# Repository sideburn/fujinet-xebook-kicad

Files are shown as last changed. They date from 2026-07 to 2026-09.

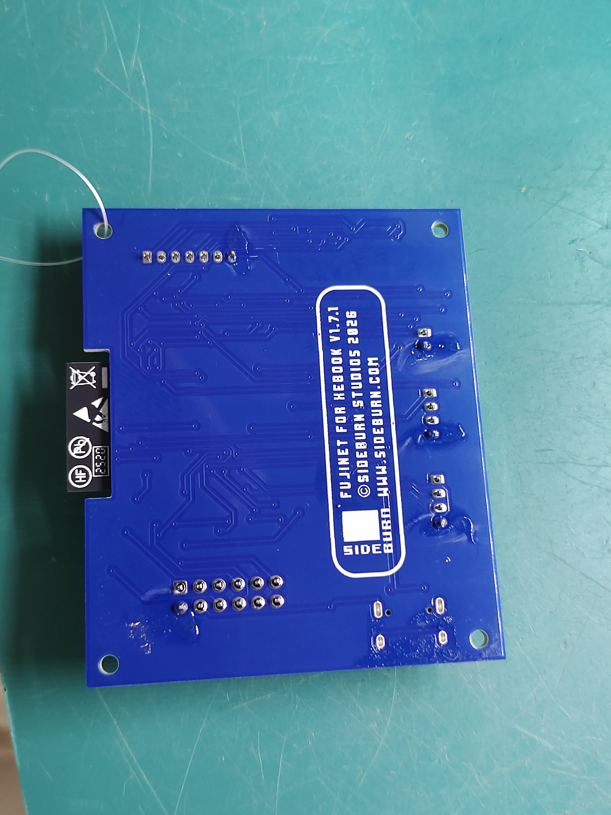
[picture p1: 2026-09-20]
Fab/as-built-1.0-PCBWay-T-1D22W845207A/Edits to PCBway/T-1D22W845207A/4716ba6a605b2589e788d23b78427af0.jpg

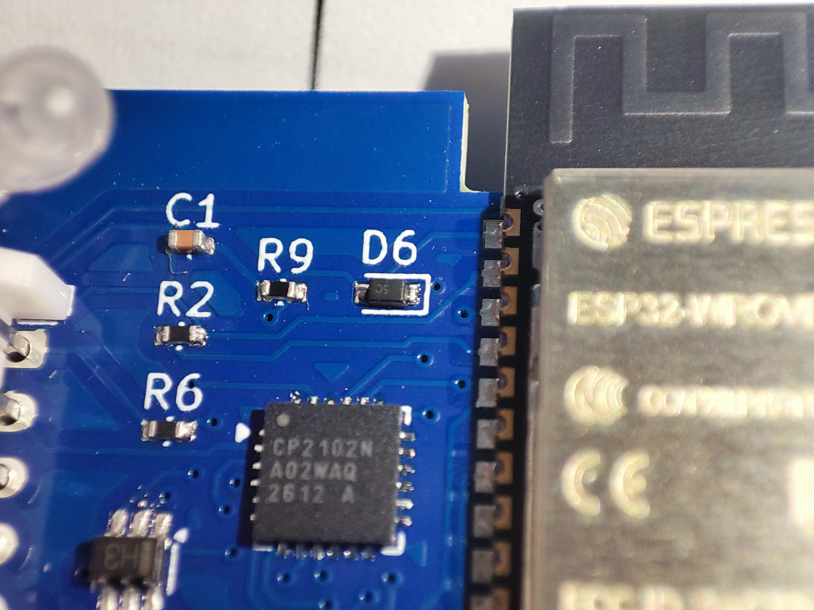
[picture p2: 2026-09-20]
Fab/as-built-1.0-PCBWay-T-1D22W845207A/Edits to PCBway/T-1D22W845207A_EQPic_0812140108/1_202608121354358581770.jpg

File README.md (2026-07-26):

# FN32ROV XEBook KiCad

A KiCad rebuild of the [FujiNet](https://fujinet.online/) FN32ROV WiFi/SIO adapter for
Atari 8-bit computers, adapted for permanent internal mounting inside an XEBook laptop
build.

This project is derived from the FN32ROV-1.7.1 release in
[FujiNetWIFI/fujinet-hardware](https://github.com/FujiNetWIFI/fujinet-hardware), which is
officially certified open source hardware by [OSHWA](https://oshwa.org) (UID
[US000651](https://certification.oshwa.org/us000651.html)). The original design is in
DipTrace; this project is a from-scratch rebuild in KiCad, since DipTrace's binary file
format has no viable automated conversion path into KiCad and this revision changes
enough of the board that preserving the original layout wasn't a goal.

## Status

Work in progress — schematic and PCB layout are still being built out. Not yet fabricated
or tested.

## What's different from FN32ROV-1.7.1

- The two external Atari SIO connectors (SIO plug + SIO receptacle pass-through) are
  replaced with a single low-profile right-angle 12-pin IDC header, hardwired directly to
  the host motherboard rather than daisy-chaining external SIO peripherals.
- The three status LEDs and three tactile buttons move off the PCB onto JST pigtails, so
  they can be panel-mounted separately from the board.
- The onboard microSD socket is retained, with an added parallel breakout header so the
  card can be relocated to an external board later without a further redesign.

Everything else (ESP32-WROVER-E, CP2102N USB-serial bridge, power path, SIO level
shifters) is carried over from the original design.

## Tooling

Built with KiCad 9. `kicad-cli sch erc` / `kicad-cli pcb drc` are used to verify the
design as it's built.

## License

[CERN Open Hardware Licence Version 2 - Strongly Reciprocal](LICENSE) (CERN-OHL-S-2.0),
matching the copyleft, share-alike spirit of the original OSHWA-certified design.

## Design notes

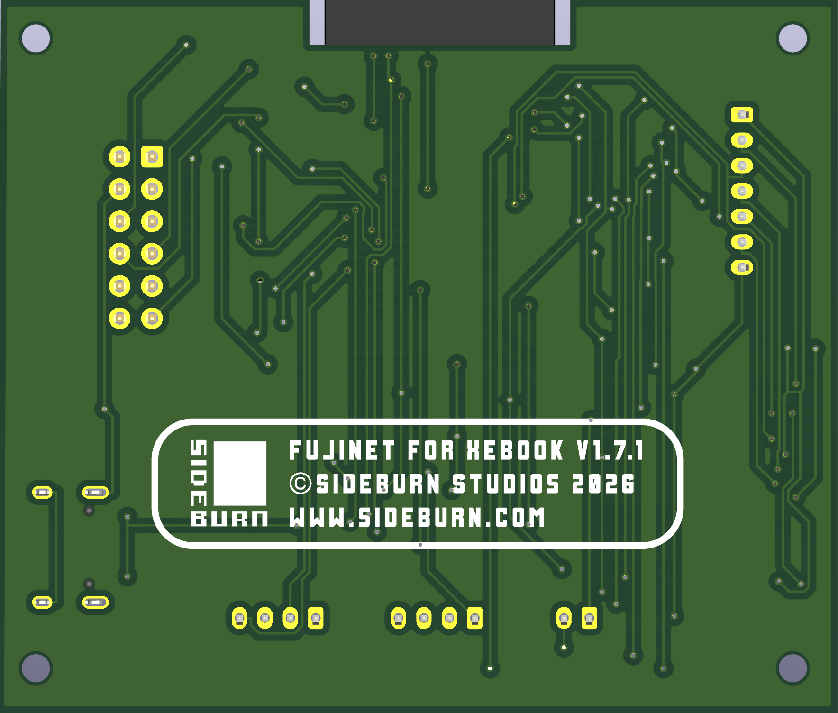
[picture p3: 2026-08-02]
Graphics/PCB_Back.png

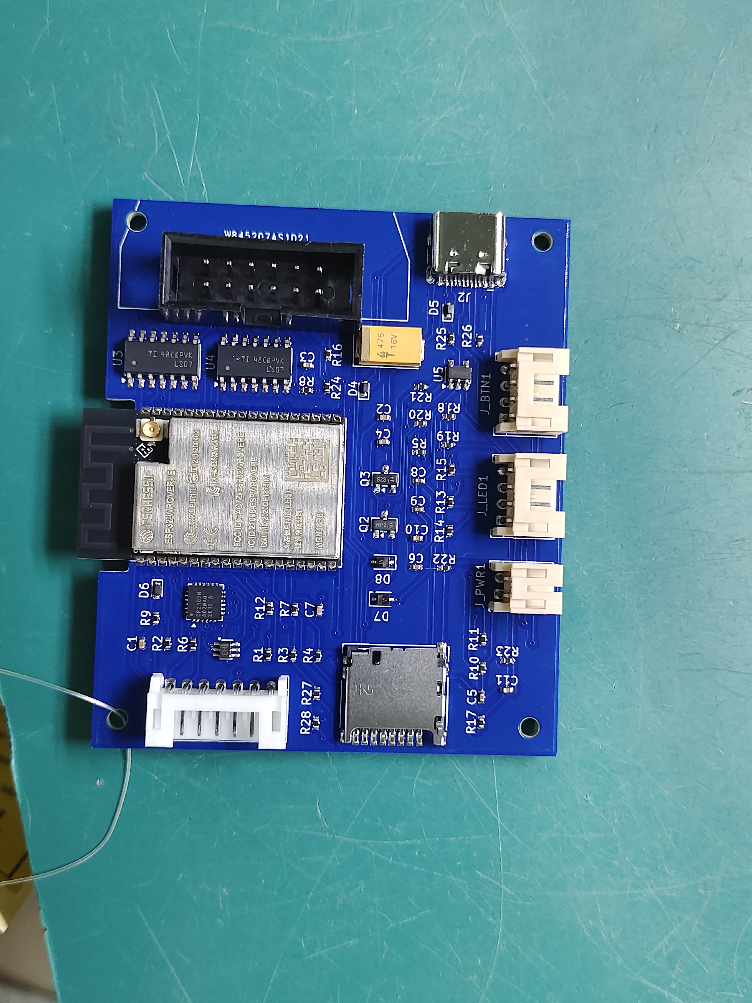
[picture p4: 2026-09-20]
Fab/as-built-1.0-PCBWay-T-1D22W845207A/Edits to PCBway/T-1D22W845207A/6a65568a0f6dcae3ce2b827522e64911.jpg

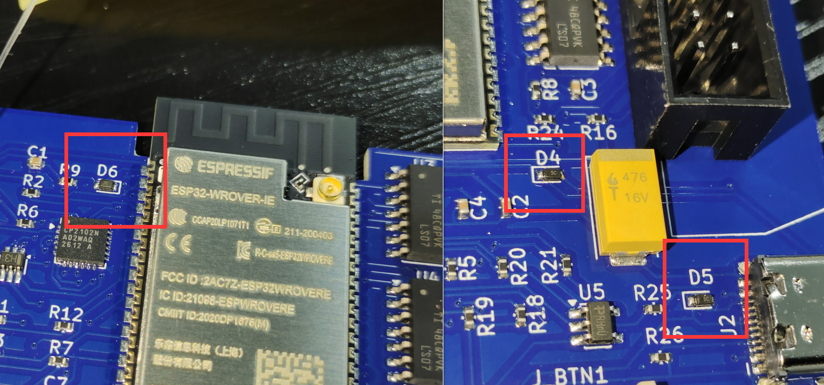
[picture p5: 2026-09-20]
Fab/as-built-1.0-PCBWay-T-1D22W845207A/Edits to PCBway/T-1D22W845207A/位号：D4,D5,D6,确认方向.png

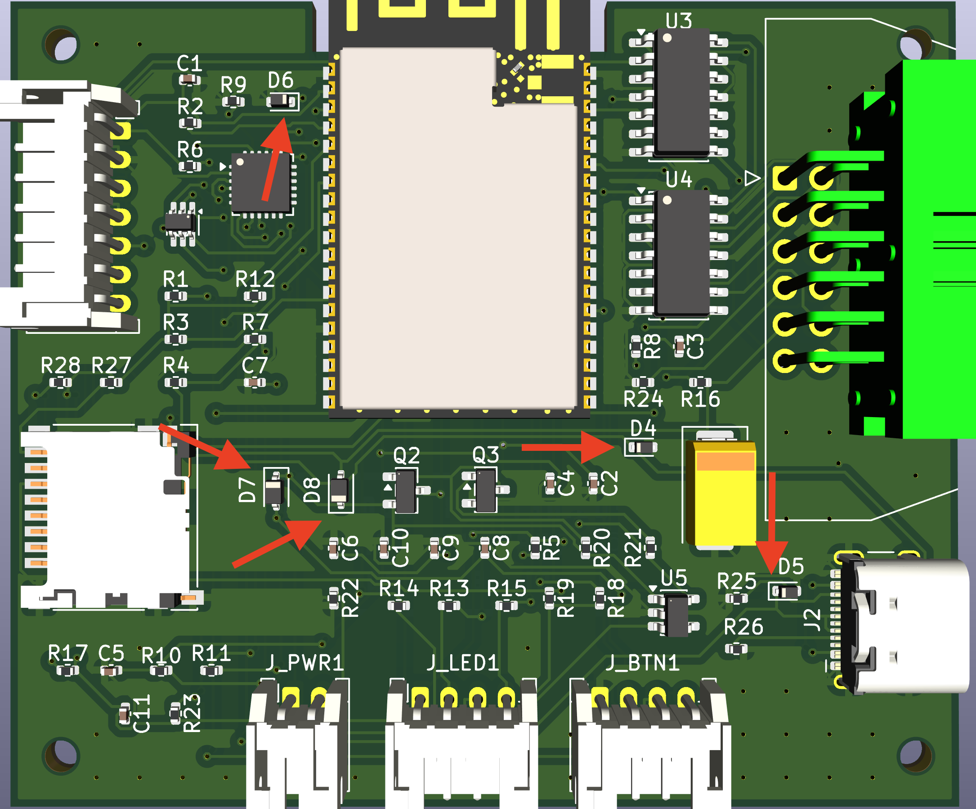
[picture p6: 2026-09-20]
Fab/as-built-1.0-PCBWay-T-1D22W845207A/Edits to PCBway/T-1D22W845207A_EQPic_0812140108/Screenshot 2026-08-11 at 11.21.06 PM.png

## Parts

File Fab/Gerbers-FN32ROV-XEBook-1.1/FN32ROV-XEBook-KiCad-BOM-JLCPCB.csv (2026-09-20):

Comment | Designator | Footprint | LCSC Part #
4.7uF 6.3V | C1 | Capacitor_SMD:C_0402_1005Metric | C23733
4.7uF 6.3V | C2 | Capacitor_SMD:C_0402_1005Metric | C23733
4.7uF 6.3V | C3 | Capacitor_SMD:C_0402_1005Metric | C23733
4.7uF 6.3V | C4 | Capacitor_SMD:C_0402_1005Metric | C23733
4.7uF 6.3V | C7 | Capacitor_SMD:C_0402_1005Metric | C23733
4.7uF 6.3V | C10 | Capacitor_SMD:C_0402_1005Metric | C23733
4.7uF 6.3V | C11 | Capacitor_SMD:C_0402_1005Metric | C23733
0.1uF 6.3V | C5 | Capacitor_SMD:C_0402_1005Metric | C1525
0.1uF 6.3V | C6 | Capacitor_SMD:C_0402_1005Metric | C1525
0.1uF 6.3V | C8 | Capacitor_SMD:C_0402_1005Metric | C1525
0.1uF 6.3V | C9 | Capacitor_SMD:C_0402_1005Metric | C1525
47uF 10V | C12 | Capacitor_Tantalum_SMD:CP_EIA-7343-31_Kemet-D | C503930
ESD5Z5.0T1G | D4 | Diode_SMD:D_SOD-523 | C2879719
ESD5Z5.0T1G | D5 | Diode_SMD:D_SOD-523 | C2879719
ESD5Z5.0T1G | D6 | Diode_SMD:D_SOD-523 | C2879719
PMEG2010BEA,115 | D7 | Diode_SMD:D_SOD-323 | C455041
PMEG2010BEA,115 | D8 | Diode_SMD:D_SOD-323 | C455041
USB-C 16P | J2 | LocalOverrides:USB_C_Receptacle_HCTL_HC-TYPE-C-16P-01A | C2894897
BTN_JST | J_BTN1 | Connector_JST:JST_PH_S4B-PH-K_1x04_P2.00mm_Horizontal | C265452
LED_JST | J_LED1 | Connector_JST:JST_PH_S4B-PH-K_1x04_P2.00mm_Horizontal | C265452
PWR_SW_JST | J_PWR1 | Connector_JST:JST_PH_S2B-PH-K_1x02_P2.00mm_Horizontal | C265016
SD_JST | J_SD1 | Connector_JST:JST_PH_S7B-PH-K_1x07_P2.00mm_Horizontal | C157917
SIO_IDC | J_SIO1 | Connector_IDC:IDC-Header_2x06_P2.54mm_Vertical | C9136
UMH3NTN | Q1 | Package_TO_SOT_SMD:SOT-363_SC-70-6 | C123008
DMP2035U-7 | Q2 | Package_TO_SOT_SMD:SOT-23 | C110499
DMG2302U | Q3 | Package_TO_SOT_SMD:SOT-23 | C96613
10K | R1 | Resistor_SMD:R_0402_1005Metric | C25744
10K | R2 | Resistor_SMD:R_0402_1005Metric | C25744
10K | R3 | Resistor_SMD:R_0402_1005Metric | C25744
10K | R5 | Resistor_SMD:R_0402_1005Metric | C25744
10K | R6 | Resistor_SMD:R_0402_1005Metric | C25744
10K | R8 | Resistor_SMD:R_0402_1005Metric | C25744
10K | R12 | Resistor_SMD:R_0402_1005Metric | C25744
10K | R17 | Resistor_SMD:R_0402_1005Metric | C25744
10K | R18 | Resistor_SMD:R_0402_1005Metric | C25744
10K | R19 | Resistor_SMD:R_0402_1005Metric | C25744
10K | R20 | Resistor_SMD:R_0402_1005Metric | C25744
10K | R22 | Resistor_SMD:R_0402_1005Metric | C25744
10K | R23 | Resistor_SMD:R_0402_1005Metric | C25744
10K | R27 | Resistor_SMD:R_0402_1005Metric | C25744
10K | R28 | Resistor_SMD:R_0402_1005Metric | C25744
1.2k | R4 | Resistor_SMD:R_0402_1005Metric | C25862
10K | R15 | Resistor_SMD:R_0402_1005Metric | C25744
2k | R7 | Resistor_SMD:R_0402_1005Metric | C413086
47.5K | R9 | Resistor_SMD:R_0402_1005Metric | C25896
1k | R10 | Resistor_SMD:R_0402_1005Metric | C11702
2.7k | R13 | Resistor_SMD:R_0402_1005Metric | C413089
30k | R14 | Resistor_SMD:R_0402_1005Metric | C25776
1k | R21 | Resistor_SMD:R_0402_1005Metric | C11702
22.1K | R11 | Resistor_SMD:R_0402_1005Metric | C163478
4.7K | R16 | Resistor_SMD:R_0402_1005Metric | C413001
2K | R24 | Resistor_SMD:R_0402_1005Metric | C413086
5.1K | R25 | Resistor_SMD:R_0402_1005Metric | C25905
5.1K | R26 | Resistor_SMD:R_0402_1005Metric | C25905
DM3D-SF | SD1 | Connector_Card:microSD_HC_Hirose_DM3D-SF | C719027
ESP32-WROVER-E-N16R8 | U1 | Espressif:ESP32-WROVER-E | C529589
CP2102N-A02-GQFN24R | U2 | Package_DFN_QFN:QFN-24-1EP_4x4mm_P0.5mm_EP2.6x2.6mm | C969151
74LS07DR | U3 | Package_SO:SOIC-14_3.9x8.7mm_P1.27mm | C371970
74LS07DR | U4 | Package_SO:SOIC-14_3.9x8.7mm_P1.27mm | C371970
XC6220B331MR | U5 | Package_TO_SOT_SMD:SOT-23-5 | C3040644

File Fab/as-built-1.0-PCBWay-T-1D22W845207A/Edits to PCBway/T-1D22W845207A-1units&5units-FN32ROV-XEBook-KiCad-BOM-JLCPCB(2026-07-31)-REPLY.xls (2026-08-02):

PCBWay Bom Quotation, Product No.:T-1D22W845207A
Item # | *Designator | *Qty | Manufacturer | *Mfg Part # | Description / Value | *Package/Footprint | *Unit Price(1 unit) | *Total | *Delivery Time | *Unit Price(5 units) | *Total | *Delivery Time | *Actual Purchase Mfg Part # | *PCBWay Note | Customer Reply | PCBWay Update
1 | C1 C2 C3 C4 C7 C10 C11 | 7 | SAMSUNG(三星) | C23733 | 4.7uF 6.3V | Capacitor_SMD:C_0402_1005Metric | $0.160 | $0.000 |  | $0.046 | $0.000 |  | CL05A475MP5NRNC | The correct voltage for the listed Part Number [CL05A475MP5NRNC] is indeed [10V], not [6.3V].Please confirm. | Confirmed, the 10V-rated substitute is acceptable. It exceeds our 6.3V spec (more headroom), no functional impact. Please proceed.
2 | C5 C6 C8 C9 | 4 | SAMSUNG(三星) | C1525 | 0.1uF 6.3V | Capacitor_SMD:C_0402_1005Metric | $0.151 | $0.000 |  | $0.050 | $0.000 |  | CL05B104KO5NNNC | The correct voltage for the listed Part Number [CL05B104KO5NNNC] is indeed [16V], not [6.3V].Please confirm. | Confirmed, the 16V-rated substitute is acceptable. It exceeds our 6.3V spec (more headroom), no functional impact. Please proceed.
3 | C12 | 1 | TORCH(火炬) | C503930 | 47uF 10V | Capacitor_Tantalum_SMD:CP_EIA-7343-31_Kemet-D | $3.001 | $0.000 |  | $1.491 | $0.000 |  | CA45-D-16V-47uF-K | The correct voltage for the listed Part Number [CA45-D-16V-47uF-K] is indeed [16V], not [10V].Please confirm. | Confirmed, the 16V-rated substitute is acceptable. It exceeds our 10V spec (more headroom), no functional impact. Please proceed.
4 | D4 D5 D6 | 3 | CBI(创基) | C2879719 | ESD5Z5.0T1G | Diode_SMD:D_SOD-523 | $0.328 | $0.000 |  | $0.066 | $0.000 |  | DESD5Z5.0
5 | D7 D8 | 2 | Nexperia(安世) | C82288 | PMEG2010ER,115 | Diode_SMD:D_SOD-323 | $0.239 | $0.000 |  | $0.102 | $0.000 |  | PMEG2010BEA,115
6 | J2 | 1 | HCTL(华灿天禄) | C2894897 | USB-C 16P | LocalOverrides:USB_C_Receptacle_HCTL_HC-TYPE-C-16P-01A | $0.904 | $0.000 |  | $0.259 | $0.000 |  | HC-TYPE-C-16P-01A
7 | J_BTN1 | 1 | JST | C265452 | BTN_JST | Connector_JST:JST_PH_S4B-PH-K_1x04_P2.00mm_Horizontal | $1.587 | $0.000 |  | $0.317 | $0.000 |  | S4B-PH-K(LF)(SN)
8 | J_LED1 | 1 | JST | C265452 | LED_JST | Connector_JST:JST_PH_S4B-PH-K_1x04_P2.00mm_Horizontal | $1.587 | $0.000 |  | $0.317 | $0.000 |  | S4B-PH-K(LF)(SN)
9 | J_PWR1 | 1 | JST | C265016 | PWR_SW_JST | Connector_JST:JST_PH_S2B-PH-K_1x02_P2.00mm_Horizontal | $0.869 | $0.000 |  | $0.174 | $0.000 |  | S2B-PH-K(LF)(SN)
10 | J_SD1 | 1 | JST | C157917 | SD_JST | Connector_JST:JST_PH_S7B-PH-K_1x07_P2.00mm_Horizontal | $1.480 | $0.000 |  | $0.296 | $0.000 |  | S7B-PH-K-S(LF)(SN)
11 | J_SIO1 | 1 |  |  | SIO_IDC | LocalOverrides:IDC-Header_2x06_P2.54mm_Latch_Horizontal | $0.391 | $0.000 |  | $0.130 | $0.000 |  | 2.54-2*6P简牛
12 | Q1 | 1 | ROHM(罗姆) | C123008 | UMH3NTN | Package_TO_SOT_SMD:SOT-363_SC-70-6 | $1.068 | $0.000 |  | $0.193 | $0.000 |  | UMH3NTN
13 | Q2 | 1 | DIODES(美台) | C110499 | DMP2035U-7 | Package_TO_SOT_SMD:SOT-23 | $0.517 | $0.000 |  | $0.172 | $0.000 |  | DMP2035U-7
14 | Q3 | 1 | DIODES(美台) | C96613 | DMG2302U | Package_TO_SOT_SMD:SOT-23 | $0.316 | $0.000 |  | $0.105 | $0.000 |  | DMG2302U-7
15 | R1 R2 R3 R5 R6 R8 R12 R17 R18 R19 R20 R22 R23 R27 R28 | 15 | UNI-ROYAL(厚声) | C25744 | 10K | Resistor_SMD:R_0402_1005Metric | $0.015 | $0.000 |  | $0.005 | $0.000 |  | 0402WGF1002TCE
16 | R4 R15 | 2 | UNI-ROYAL(厚声) | C25862 | 1.2k | Resistor_SMD:R_0402_1005Metric | $0.069 | $0.000 |  | $0.019 | $0.000 |  | 0402WGF1201TCE
17 | R7 R24 | 2 | PANASONIC(松下) | C413086 | 2k | Resistor_SMD:R_0402_1005Metric | $0.254 | $0.000 |  | $0.069 | $0.000 |  | ERJ2RKF2001X
18 | R9 | 1 | UNI-ROYAL(厚声) | C25896 | 47.5K | Resistor_SMD:R_0402_1005Metric | $0.132 | $0.000 |  | $0.032 | $0.000 |  | 0402WGF4752TCE
19 | R10 R14 R21 | 3 | UNI-ROYAL(厚声) | C11702 | 1k | Resistor_SMD:R_0402_1005Metric | $0.048 | $0.000 |  | $0.015 | $0.000 |  | 0402WGF1001TCE
20 | R11 | 1 | YAGEO(国巨) | C163478 | 22.1K | Resistor_SMD:R_0402_1005Metric | $0.132 | $0.000 |  | $0.032 | $0.000 |  | RC0402FR-0722K1L
21 | R16 | 1 | PANASONIC(松下) | C413001 | 4.7K | Resistor_SMD:R_0402_1005Metric | $0.485 | $0.000 |  | $0.116 | $0.000 |  | ERJ2GEJ472X
22 | R25 R26 | 2 | UNI-ROYAL(厚声) | C25905 | 5.1K | Resistor_SMD:R_0402_1005Metric | $0.069 | $0.000 |  | $0.019 | $0.000 |  | 0402WGF5101TCE
23 | SD1 | 1 | HRS(广濑) | C719027 | DM3D-SF | Connector_Card:microSD_HC_Hirose_DM3D-SF | $2.903 | $0.000 |  | $2.053 | $0.000 |  | DM3D-SF
24 | U1 | 1 | ESPRESSIF(乐鑫) | C701352 | ESP32-WROVER-IE-N16R8 | Espressif:ESP32-WROVER-E | $4.852 | $0.000 |  | $4.852 | $0.000 |  | ESP32-WROVER-IE-N16R8
25 | U2 | 1 | SKYWORKS/SILICON LABS(芯科) | C969151 | CP2102N-A02-GQFN24R | Package_DFN_QFN:QFN-24-1EP_4x4mm_P0.5mm_EP2.6x2.6mm | $4.830 | $0.000 |  | $3.248 | $0.000 |  | CP2102N-A02-GQFN24R
26 | U3 U4 | 2 | TI(德州仪器) | C371970 | 74LS07DR | Package_SO:SOIC-14_3.9x8.7mm_P1.27mm | $0.290 | $0.000 |  | $0.213 | $0.000 |  | SN74LS07DR
27 | U5 | 1 | TECH PUBLIC(台舟) | C3040644 | XC6220B331MR | Package_TO_SOT_SMD:SOT-23-5 | $0.235 | $0.000 |  | $0.141 | $0.000 |  | XC6220B331MR
28 | R13 | 1 |  | ERJ2RKF2701X |  |  | $0.441 | $0.000 |  | $0.116 | $0.000
 |  |  |  |  |  |  | Component Cost | $0.00 |  | Component Cost | $0.00
 |  |  |  |  |  |  | Assembly Cost |  |  | Assembly Cost
 |  |  |  |  |  |  | PCB Cost |  |  | PCB Cost
 |  |  |  |  |  |  | V2 Member 2% off | $0.00 |  | V2 Member 2% off | $0.00
 |  |  |  |  |  |  | All Total 1 Units | $0.00 |  | All Total 5 Units | $0.00
*Actual Purchase Mfg Part # *PCBWay Note请确认；客户bom中的位号是散开的，将位号整合了，请确认；麻烦客户下次将相同参数的型号的位号放在同一行

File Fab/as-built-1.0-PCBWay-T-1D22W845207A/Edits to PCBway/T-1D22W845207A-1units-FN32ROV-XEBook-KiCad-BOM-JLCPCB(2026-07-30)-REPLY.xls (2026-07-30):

PCBWay Bom Quotation, Product No.:T-1D22W845207A
Item # | *Designator | *Qty | Manufacturer | *Mfg Part # | Description / Value | *Package/Footprint | *Unit Price(1 unit) | *Total | *Delivery Time | *Actual Purchase Mfg Part # | *PCBWay Note | Customer Reply | PCBWay Update
1 | C1 C2 C3 C4 C7 C10 C11 | 7 | SAMSUNG(三星) | C23733 | 4.7uF 6.3V | Capacitor_SMD:C_0402_1005Metric | $0.160 | $1.120 |  | CL05A475MP5NRNC | The correct voltage for the listed Part Number [CL05A475MP5NRNC] is indeed [10V], not [6.3V].Please confirm. | Confirmed, the 10V-rated substitute is acceptable. It exceeds our 6.3V spec (more headroom), no functional impact. Please proceed.
2 | C5 C6 C8 C9 | 4 | SAMSUNG(三星) | C1525 | 0.1uF 6.3V | Capacitor_SMD:C_0402_1005Metric | $0.151 | $0.604 |  | CL05B104KO5NNNC | The correct voltage for the listed Part Number [CL05B104KO5NNNC] is indeed [16V], not [6.3V].Please confirm. | Confirmed, the 16V-rated substitute is acceptable. It exceeds our 6.3V spec (more headroom), no functional impact. Please proceed.
3 | C12 | 1 | TORCH(火炬) | C503930 | 47uF 10V | Capacitor_Tantalum_SMD:CP_EIA-7343-31_Kemet-D | $3.001 | $3.001 |  | CA45-D-16V-47uF-K | The correct voltage for the listed Part Number [CA45-D-16V-47uF-K] is indeed [16V], not [10V].Please confirm. | Confirmed, the 16V-rated substitute is acceptable. It exceeds our 10V spec (more headroom), no functional impact. Please proceed.
4 | D4 D5 D6 | 3 | CBI(创基) | C2879719 | ESD5Z5.0T1G | Diode_SMD:D_SOD-523 | $0.328 | $0.984 |  | DESD5Z5.0
5 | D7 D8 | 2 | Nexperia(安世) | C82288 | PMEG2010ER,115 | Diode_SMD:D_SOD-323 | $0.492 | $0.984 |  | PMEG2010ER,115 | The correct package for the listed Part Number [PMEG2010ER,115] is indeed [SOD-123W], not [Diode_SMD:D_SOD-323].Please confirm. | You are correct - PMEG2010ER,115 is packaged in SOD-123W, not SOD-323; that was an error in our BOM. Please do NOT substitute the footprint. Instead replace the part entirely with Nexperia PMEG2010BEA,115 (LCSC C455041), a direct electrical equivalent (20V/1A Schottky, low Vf) that is genuinely packaged in SOD-323, matching our PCB footprint. Updated BOM re-uploaded.
6 | J2 | 1 | HCTL(华灿天禄) | C2894897 | USB-C 16P | LocalOverrides:USB_C_Receptacle_HCTL_HC-TYPE-C-16P-01A | $0.904 | $0.904 |  | HC-TYPE-C-16P-01A
7 | J_BTN1 | 1 | JST | C265452 | BTN_JST | Connector_JST:JST_PH_S4B-PH-K_1x04_P2.00mm_Horizontal | $1.587 | $1.587 |  | S4B-PH-K(LF)(SN)
8 | J_LED1 | 1 | JST | C265452 | LED_JST | Connector_JST:JST_PH_S4B-PH-K_1x04_P2.00mm_Horizontal | $1.587 | $1.587 |  | S4B-PH-K(LF)(SN)
9 | J_PWR1 | 1 | JST | C265016 | PWR_SW_JST | Connector_JST:JST_PH_S2B-PH-K_1x02_P2.00mm_Horizontal | $0.869 | $0.869 |  | S2B-PH-K(LF)(SN)
10 | J_SD1 | 1 | JST | C157917 | SD_JST | Connector_JST:JST_PH_S7B-PH-K_1x07_P2.00mm_Horizontal | $1.480 | $1.480 |  | S7B-PH-K-S(LF)(SN)
11 | J_SIO1 | 1 |  |  | SIO_IDC | LocalOverrides:IDC-Header_2x06_P2.54mm_Latch_Horizontal |  |  |  |  | pls provide exact part number and brand | Please source and assemble this connector: BOOMELE 2.54-2*6P, LCSC C9136 (2x6, 12-pin, 2.54mm pitch straight IDC box header, 43,950 in stock). Pad footprint matches our design either way; if a latching/ejector version is preferred for cable retention, please substitute an equivalent latch variant at the same pitch and pin count.
12 | Q1 | 1 | ROHM(罗姆) | C123008 | UMH3NTN | Package_TO_SOT_SMD:SOT-363_SC-70-6 | $1.068 | $1.068 |  | UMH3NTN
13 | Q2 | 1 | DIODES(美台) | C110499 | DMP2035U-7 | Package_TO_SOT_SMD:SOT-23 | $0.517 | $0.517 |  | DMP2035U-7
14 | Q3 | 1 | DIODES(美台) | C96613 | DMG2302U | Package_TO_SOT_SMD:SOT-23 | $0.316 | $0.316 |  | DMG2302U-7
15 | R1 R2 R3 R5 R6 R8 R12 R17 R18 R19 R20 R22 R23 R27 R28 | 15 | UNI-ROYAL(厚声) | C25744 | 10K | Resistor_SMD:R_0402_1005Metric | $0.015 | $0.225 |  | 0402WGF1002TCE
16 | R4 R15 | 2 | UNI-ROYAL(厚声) | C25862 | 1.2k | Resistor_SMD:R_0402_1005Metric | $0.069 | $0.138 |  | 0402WGF1201TCE
17 | R7 R24 | 2 | PANASONIC(松下) | C413086 | 2k | Resistor_SMD:R_0402_1005Metric | $0.254 | $0.508 |  | ERJ2RKF2001X
18 | R9 | 1 | UNI-ROYAL(厚声) | C25896 | 47.5K | Resistor_SMD:R_0402_1005Metric | $0.132 | $0.132 |  | 0402WGF4752TCE
19 | R10 R13 R14 R21 | 4 | UNI-ROYAL(厚声) | C11702 | 1k | Resistor_SMD:R_0402_1005Metric | $0.038 | $0.152 |  | 0402WGF1001TCE |  | R13 must be split out of this group - it is 2.7kΩ (LCSC C413089, Panasonic ERJ2RKF2701X), NOT 1kΩ. Only R10, R14, and R21 remain at 1kΩ (LCSC C11702). This looks like it was quoted from an outdated BOM revision. Updated BOM (with R13 as its own 2.7kΩ line) has been re-uploaded - please requote based on that file.
20 | R11 | 1 | YAGEO(国巨) | C163478 | 22.1K | Resistor_SMD:R_0402_1005Metric | $0.132 | $0.132 |  | RC0402FR-0722K1L
21 | R16 | 1 | PANASONIC(松下) | C413001 | 4.7K | Resistor_SMD:R_0402_1005Metric | $0.485 | $0.485 |  | ERJ2GEJ472X
22 | R25 R26 | 2 | UNI-ROYAL(厚声) | C25905 | 5.1K | Resistor_SMD:R_0402_1005Metric | $0.069 | $0.138 |  | 0402WGF5101TCE
23 | SD1 | 1 | HRS(广濑) | C719027 | DM3D-SF | Connector_Card:microSD_HC_Hirose_DM3D-SF | $2.903 | $2.903 |  | DM3D-SF
24 | U1 | 1 | ESPRESSIF(乐鑫) | C701352 | ESP32-WROVER-IE-N16R8 | Espressif:ESP32-WROVER-E | $4.852 | $4.852 |  | ESP32-WROVER-IE-N16R8
25 | U2 | 1 | SKYWORKS/SILICON LABS(芯科) | C969151 | CP2102N-A02-GQFN24R | Package_DFN_QFN:QFN-24-1EP_4x4mm_P0.5mm_EP2.6x2.6mm | $4.830 | $4.830 |  | CP2102N-A02-GQFN24R
26 | U3 U4 | 2 | TI(德州仪器) | C371970 | 74LS07DR | Package_SO:SOIC-14_3.9x8.7mm_P1.27mm | $0.290 | $0.580 |  | SN74LS07DR
27 | U5 | 1 | TECH PUBLIC(台舟) | C3040644 | XC6220B331MR | Package_TO_SOT_SMD:SOT-23-5 | $0.235 | $0.235 |  | XC6220B331MR
 |  |  |  |  |  |  | Component Cost | $30.33
 |  |  |  |  |  |  | Assembly Cost
 |  |  |  |  |  |  | PCB Cost
 |  |  |  |  |  |  | V2 Member 2% off | $0.00
 |  |  |  |  |  |  | All Total 1 Units | $30.33
*Actual Purchase Mfg Part # *PCBWay Note请确认；客户bom中的位号是散开的，将位号整合了，请确认；麻烦客户下次将相同参数的型号的位号放在同一行

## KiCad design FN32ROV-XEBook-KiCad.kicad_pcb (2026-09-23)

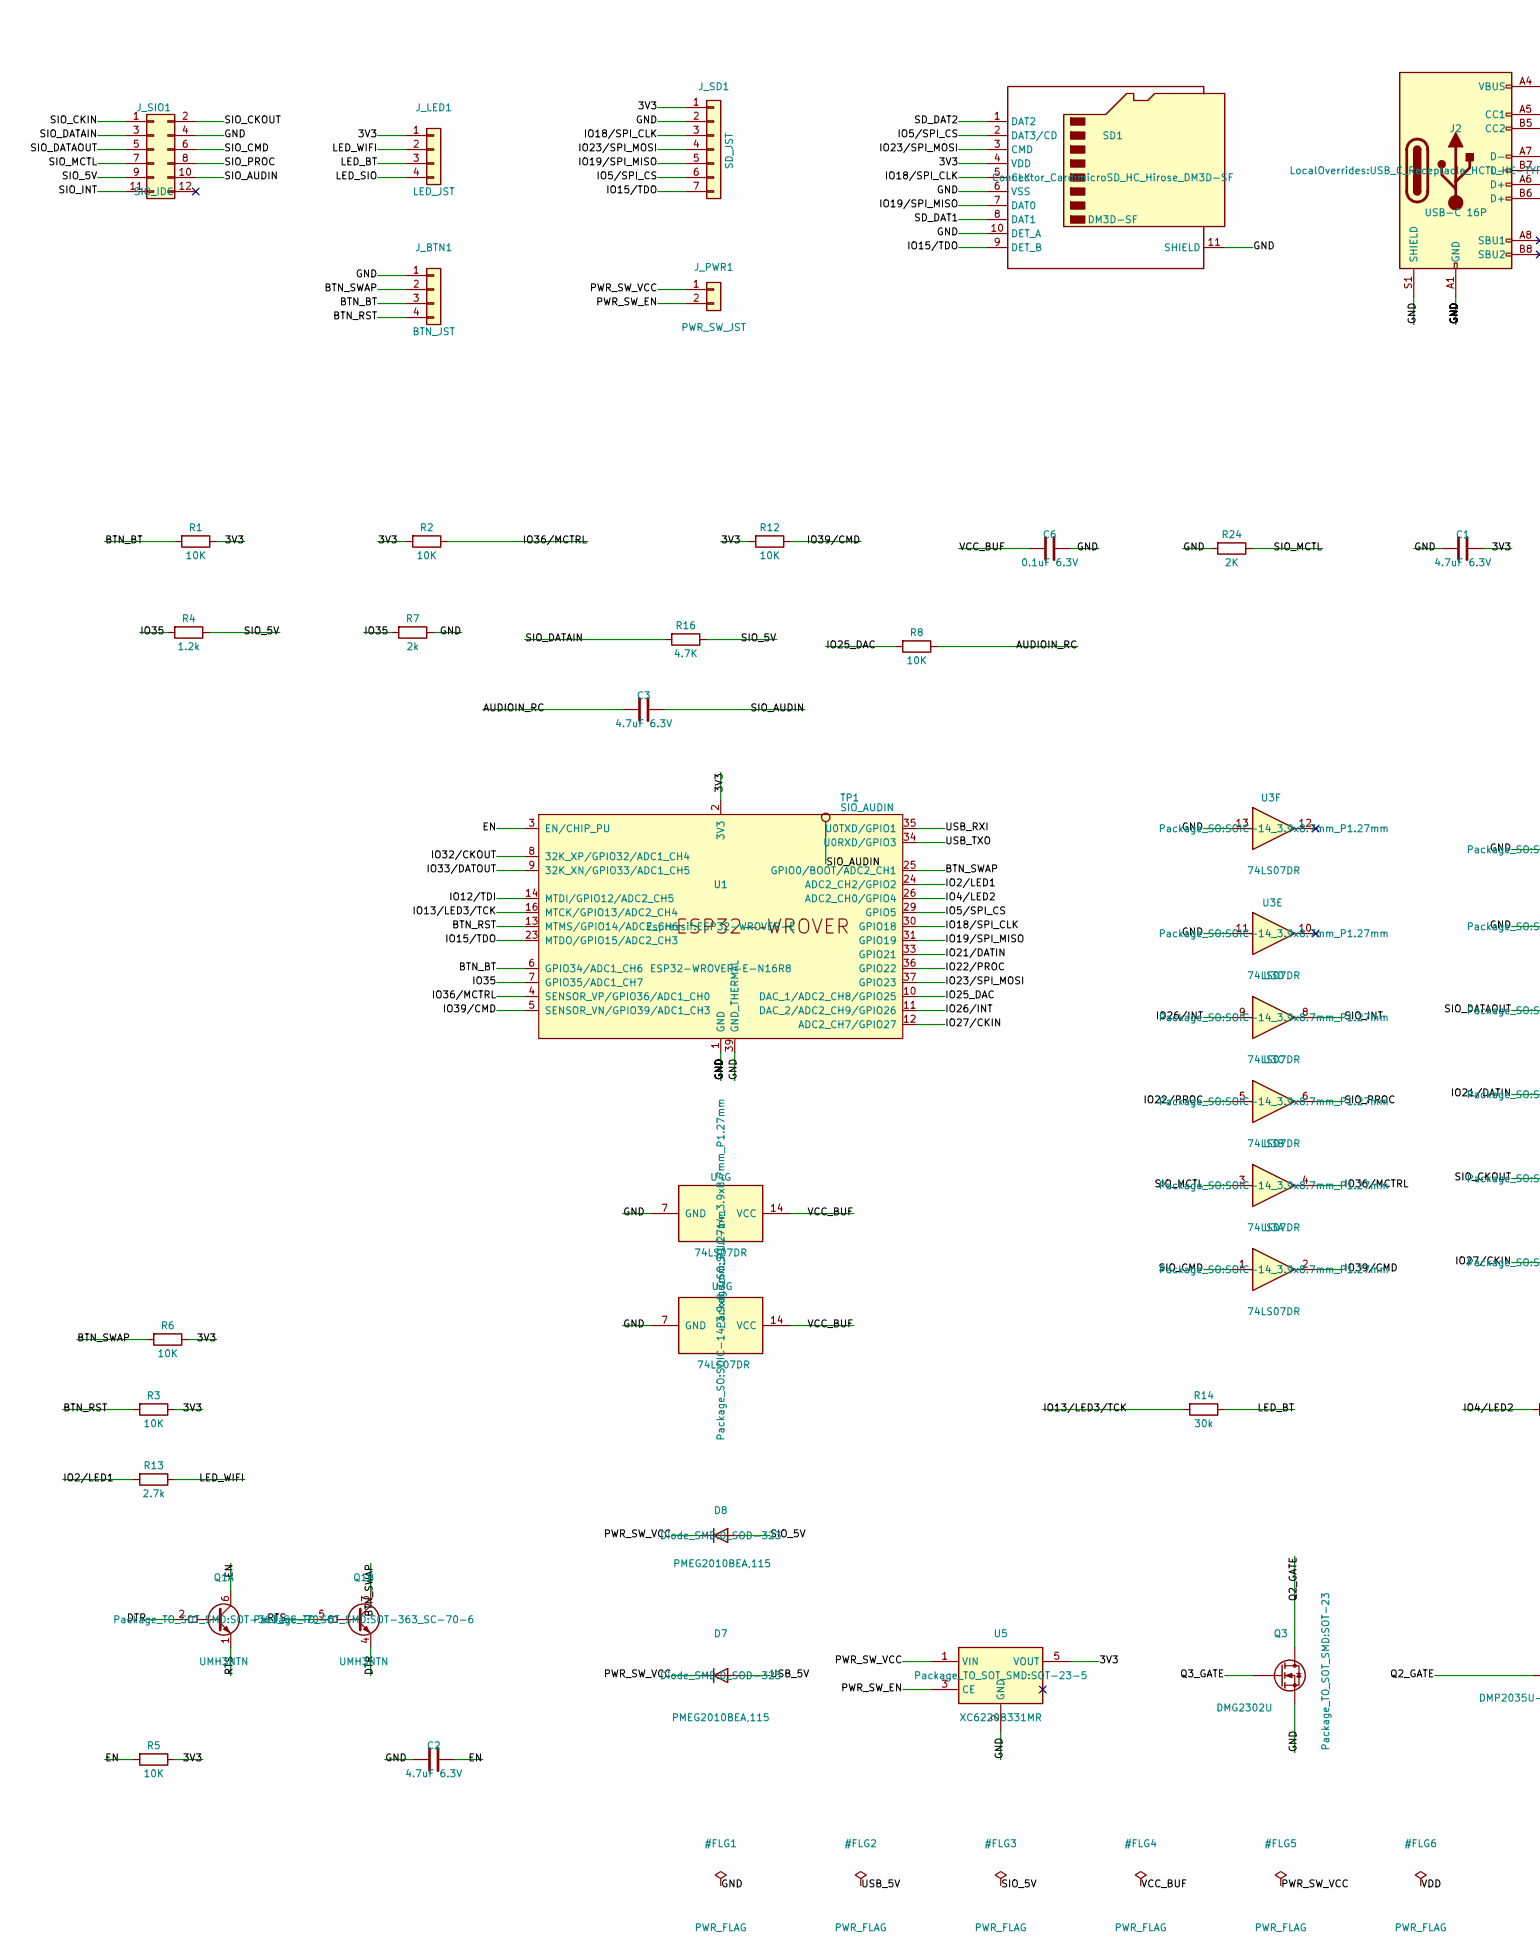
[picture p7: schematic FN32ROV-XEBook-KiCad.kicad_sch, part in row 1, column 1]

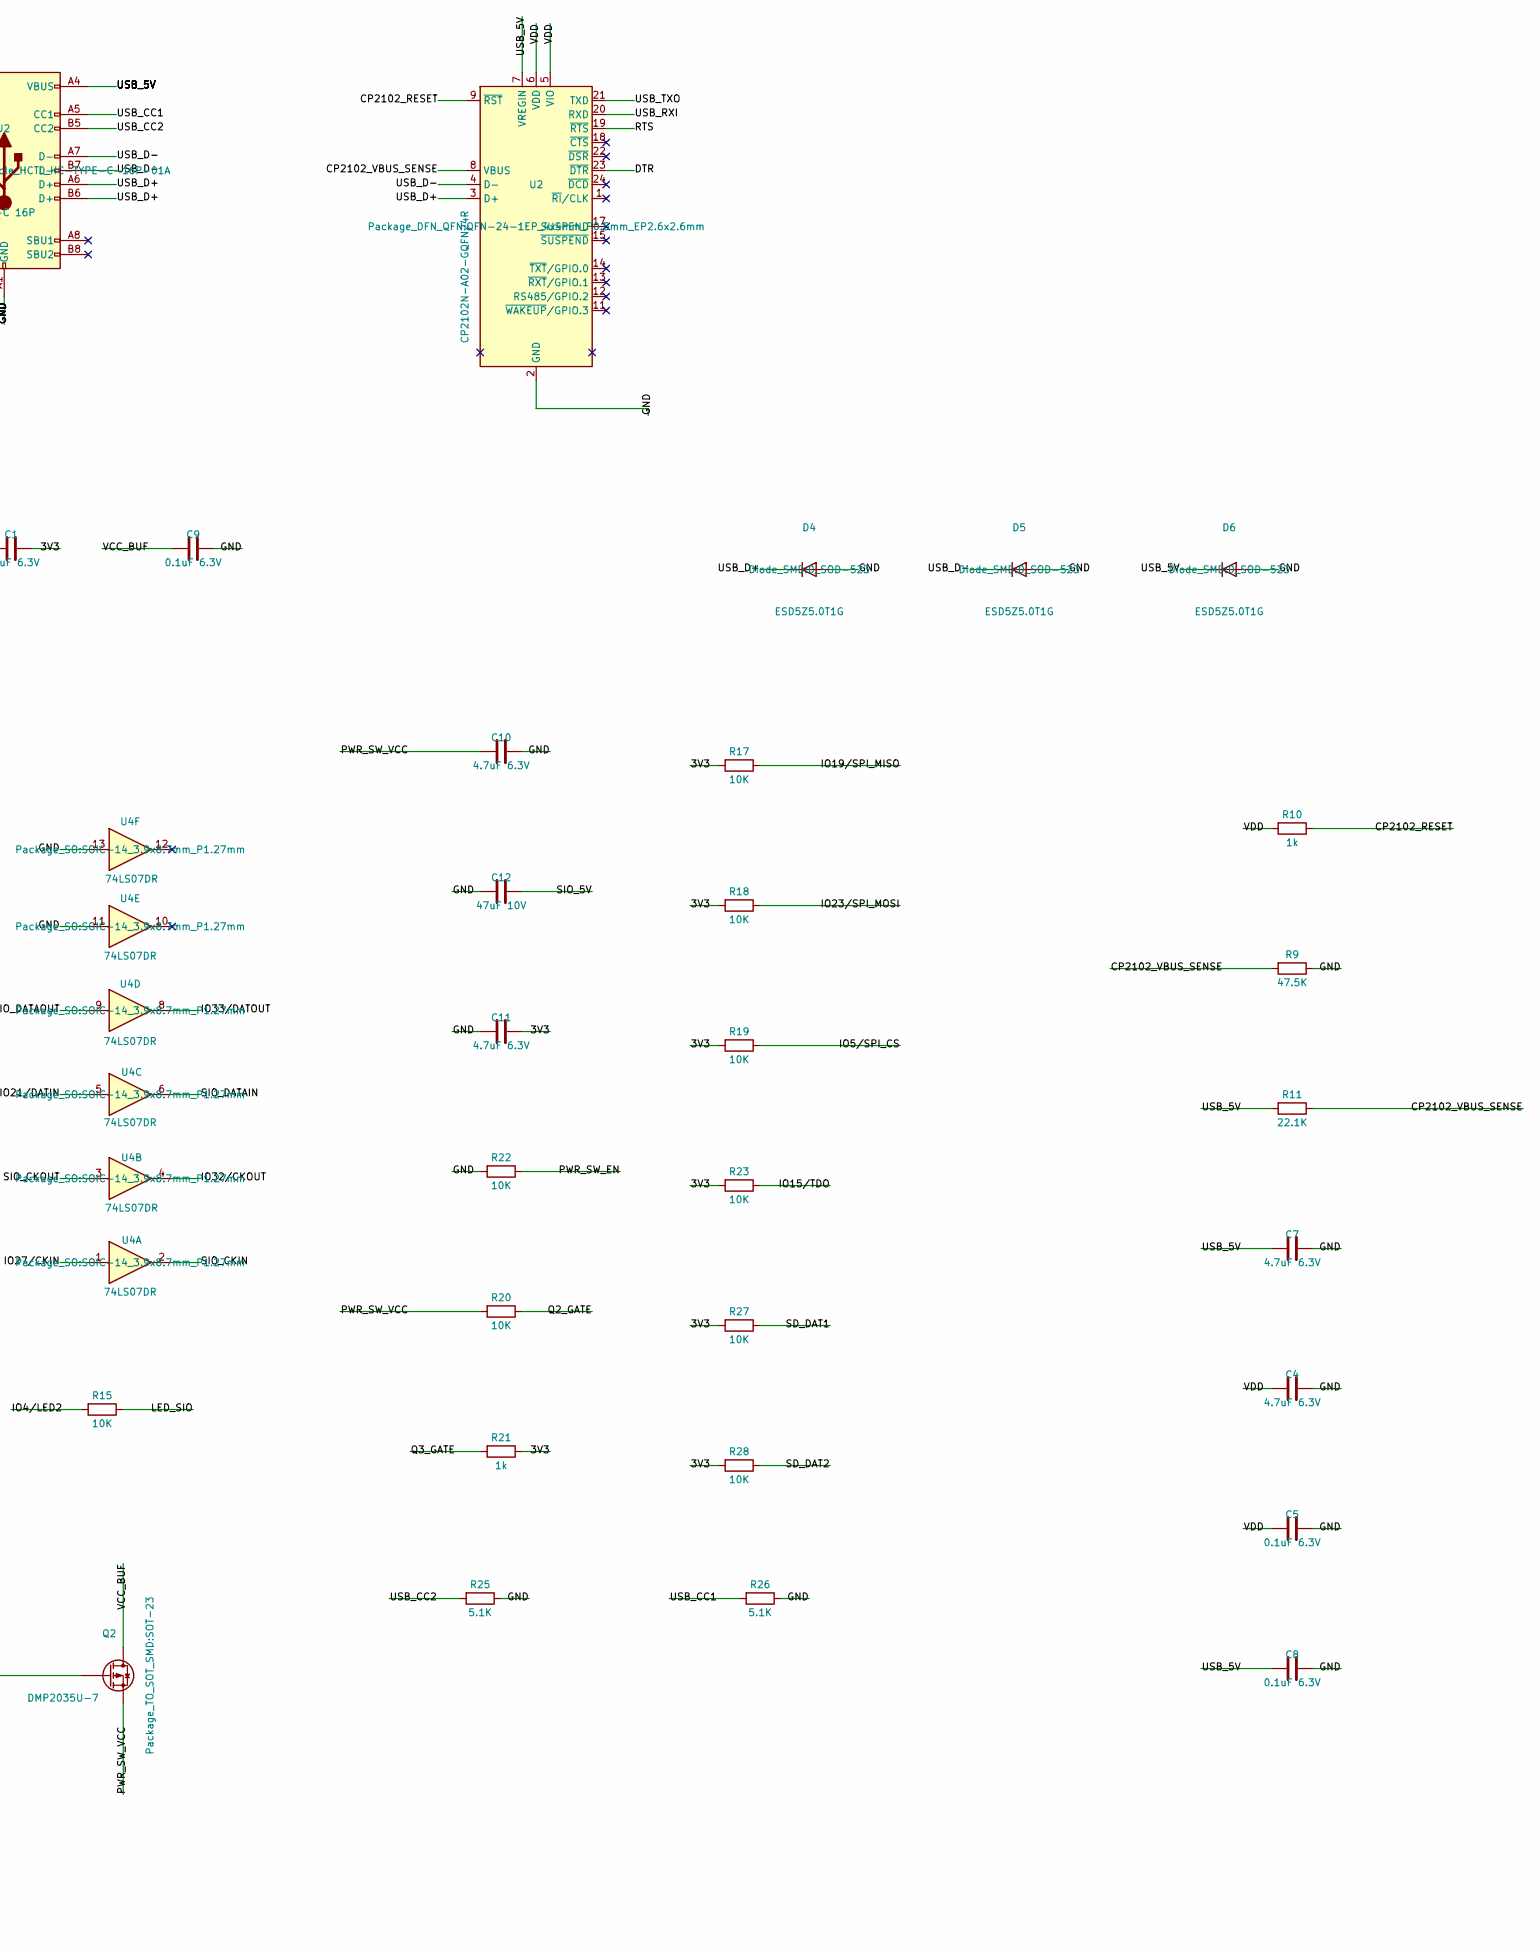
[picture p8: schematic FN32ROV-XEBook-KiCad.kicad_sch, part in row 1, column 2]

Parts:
C1, C2, C3, C4, C7, C10, C11: 4.7uF 6.3V; C_0402_1005Metric
C5, C6, C8, C9: 0.1uF 6.3V; C_0402_1005Metric
C12: 47uF 10V; CP_EIA-7343-31_Kemet-D
D4, D5, D6: ESD5Z5.0T1G; D_SOD-523
D7, D8: PMEG2010BEA,115; D_SOD-323
J2: USB-C 16P; USB_C_Receptacle_HCTL_HC-TYPE-C-16P-01A
J_BTN1: BTN_JST; JST_PH_S4B-PH-K_1x04_P2.00mm_Horizontal
J_LED1: LED_JST; JST_PH_S4B-PH-K_1x04_P2.00mm_Horizontal
J_PWR1: PWR_SW_JST; JST_PH_S2B-PH-K_1x02_P2.00mm_Horizontal
J_SD1: SD_JST; JST_PH_S7B-PH-K_1x07_P2.00mm_Horizontal
J_SIO1: SIO_IDC; IDC-Header_2x06_P2.54mm_Vertical
Q1: UMH3NTN; SOT-363_SC-70-6
Q2: DMP2035U-7; SOT-23
Q3: DMG2302U; SOT-23
R1, R2, R3, R5, R6, R8, R12, R15, R17, R18, R19, R20, R22, R23, R27, R28: 10K; R_0402_1005Metric
R4: 1.2k; R_0402_1005Metric
R7: 2k; R_0402_1005Metric
R9: 47.5K; R_0402_1005Metric
R10, R21: 1k; R_0402_1005Metric
R11: 22.1K; R_0402_1005Metric
R13: 2.7k; R_0402_1005Metric
R14: 30k; R_0402_1005Metric
R16: 4.7K; R_0402_1005Metric
R24: 2K; R_0402_1005Metric
R25, R26: 5.1K; R_0402_1005Metric
SD1: DM3D-SF; microSD_HC_Hirose_DM3D-SF
TP1: SIO_AUDIN; TestPoint_THTPad_D2.0mm_Drill1.0mm
U1: ESP32-WROVER-E-N16R8; ESP32-WROVER-E
U2: CP2102N-A02-GQFN24R; QFN-24-1EP_4x4mm_P0.5mm_EP2.6x2.6mm
U3, U4: 74LS07DR; SOIC-14_3.9x8.7mm_P1.27mm
U5: XC6220B331MR; SOT-23-5

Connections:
/3V3: C1.1, C11.1, J_LED1.1, J_SD1.1, R1.1, R2.2, R3.1, R5.1, R6.1, R12.2, R17.2, R18.2, R19.2, R21.1, R23.2, R27.2, R28.2, SD1.4 (VDD), U1.2 (3V3), U5.5 (VOUT)
/AUDIOIN_RC: C3.2, R8.1
/BTN_BT: J_BTN1.3, R1.2, U1.6 (GPIO34/ADC1_CH6)
/BTN_RST: J_BTN1.4, R3.2, U1.13 (MTMS/GPIO14/ADC2_CH6)
/BTN_SWAP: J_BTN1.2, Q1.3 (C2), R6.2, U1.25 (GPIO0/BOOT/ADC2_CH1)
/CP2102_RESET: R10.1, U2.9 (~RST)
/CP2102_VBUS_SENSE: R9.2, R11.1, U2.8 (VBUS)
/DTR: Q1.2 (B1), Q1.4 (E2), U2.23 (~DTR)
/EN: C2.1, Q1.6 (C1), R5.2, U1.3 (EN/CHIP_PU)
/GND: C1.2, C2.2, C4.1, C5.1, C6.1, C7.1, C8.1, C9.1, C10.1, C11.2, C12.2, D4.2 (A), D5.2 (A), D6.2 (A), J2.A1 (GND), J2.A12 (GND), J2.B1 (GND), J2.B12 (GND), J2.S1 (SHIELD), J_BTN1.1, J_SD1.2, J_SIO1.4, Q3.2 (S), R7.1, R9.1, R22.2, R24.2, R25.1, R26.1, SD1.6 (VSS), SD1.10 (DET_A), SD1.11 (SHIELD), U1.1 (GND), U1.15 (GND), U1.38 (GND), U1.39 (GND_THERMAL), U2.2 (GND), U2.25 (GND), U3.7 (GND), U3.11, U3.13, U4.7 (GND), U4.11, U4.13, U5.2 (GND)
/IO2/LED1: R13.2, U1.24 (ADC2_CH2/GPIO2)
/IO4/LED2: R15.2, U1.26 (ADC2_CH0/GPIO4)
/IO5/SPI_CS: J_SD1.6, R19.1, SD1.2 (DAT3/CD), U1.29 (GPIO5)
/IO12/TDI: U1.14 (MTDI/GPIO12/ADC2_CH5)
/IO13/LED3/TCK: R14.2, U1.16 (MTCK/GPIO13/ADC2_CH4)
/IO15/TDO: J_SD1.7, R23.1, SD1.9 (DET_B), U1.23 (MTDO/GPIO15/ADC2_CH3)
/IO18/SPI_CLK: J_SD1.3, SD1.5 (CLK), U1.30 (GPIO18)
/IO19/SPI_MISO: J_SD1.5, R17.1, SD1.7 (DAT0), U1.31 (GPIO19)
/IO21/DATIN: U1.33 (GPIO21), U4.5
/IO22/PROC: U1.36 (GPIO22), U3.5
/IO23/SPI_MOSI: J_SD1.4, R18.1, SD1.3 (CMD), U1.37 (GPIO23)
/IO25_DAC: R8.2, U1.10 (DAC_1/ADC2_CH8/GPIO25)
/IO26/INT: U1.11 (DAC_2/ADC2_CH9/GPIO26), U3.9
/IO27/CKIN: U1.12 (ADC2_CH7/GPIO27), U4.1
/IO32/CKOUT: U1.8 (32K_XP/GPIO32/ADC1_CH4), U4.4
/IO33/DATOUT: U1.9 (32K_XN/GPIO33/ADC1_CH5), U4.8
/IO35: R4.2, R7.2, U1.7 (GPIO35/ADC1_CH7)
/IO36/MCTRL: R2.1, U1.4 (SENSOR_VP/GPIO36/ADC1_CH0), U3.4
/IO39/CMD: R12.1, U1.5 (SENSOR_VN/GPIO39/ADC1_CH3), U3.2
/LED_BT: J_LED1.3, R14.1
/LED_SIO: J_LED1.4, R15.1
/LED_WIFI: J_LED1.2, R13.1
/PWR_SW_EN: J_PWR1.2, R22.1, U5.3 (CE)
/PWR_SW_VCC: C10.2, D7.1 (K), D8.1 (K), J_PWR1.1, Q2.2 (S), R20.2, U5.1 (VIN)
/Q2_GATE: Q2.1 (G), Q3.3 (D), R20.1
/Q3_GATE: Q3.1 (G), R21.2
/RTS: Q1.1 (E1), Q1.5 (B2), U2.19 (~RTS)
/SD_DAT1: R27.1, SD1.8 (DAT1)
/SD_DAT2: R28.1, SD1.1 (DAT2)
/SIO_5V: C12.1, D8.2 (A), J_SIO1.9, R4.1, R16.1
/SIO_AUDIN: C3.1, J_SIO1.10, TP1.1
/SIO_CKIN: J_SIO1.1, U4.2
/SIO_CKOUT: J_SIO1.2, U4.3
/SIO_CMD: J_SIO1.6, U3.1
/SIO_DATAIN: J_SIO1.3, R16.2, U4.6
/SIO_DATAOUT: J_SIO1.5, U4.9
/SIO_INT: J_SIO1.11, U3.8
/SIO_MCTL: J_SIO1.7, R24.1, U3.3
/SIO_PROC: J_SIO1.8, U3.6
/USB_5V: C7.2, C8.2, D6.1 (K), D7.2 (A), J2.A4 (VBUS), J2.A9 (VBUS), J2.B4 (VBUS), J2.B9 (VBUS), R11.2, U2.7 (VREGIN)
/USB_CC1: J2.A5 (CC1), R26.2
/USB_CC2: J2.B5 (CC2), R25.2
/USB_D+: D4.1 (K), J2.A6 (D+), J2.B6 (D+), U2.3 (D+)
/USB_D-: D5.1 (K), J2.A7 (D-), J2.B7 (D-), U2.4 (D-)
/USB_RXI: U1.35 (U0TXD/GPIO1), U2.20 (RXD)
/USB_TXO: U1.34 (U0RXD/GPIO3), U2.21 (TXD)
/VCC_BUF: C6.2, C9.2, Q2.3 (D), U3.14 (VCC), U4.14 (VCC)
/VDD: C4.2, C5.2, R10.2, U2.5 (VIO), U2.6 (VDD)

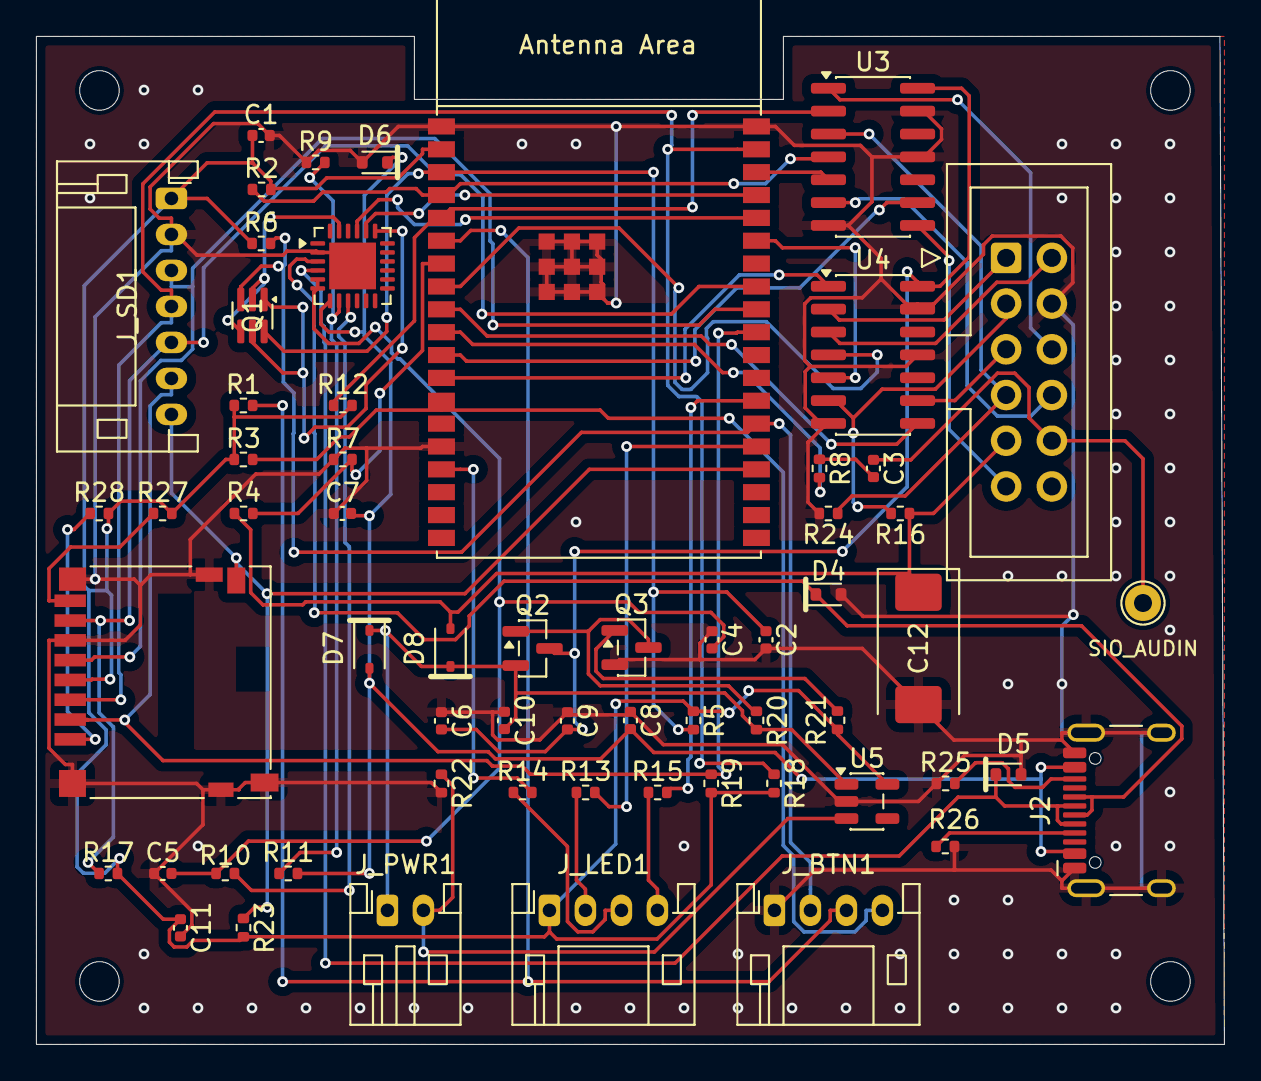
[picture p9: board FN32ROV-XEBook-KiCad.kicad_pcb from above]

Board: 2 copper layers, 66.0 x 56.0 mm, 65 parts (0 on the bottom side), 57 nets.

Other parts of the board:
MH1, MH2, MH3, MH4: MountingHole_2.2mm_M2

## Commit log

2026-07-26 Scaffold KiCad rebuild of FN32ROV for XEBook internal mount
    Empty, validated KiCad 9 project (ERC/DRC clean) as the starting point
    for rebuilding FujiNet FN32ROV-1.7.1 with an IDC SIO connector, JST
    button/LED breakouts, and an SD card breakout header.
    Claude-Session: https://claude.ai/code/session_01ATUvQCobb1cVELUyjLrcQZ
    [FN32ROV-XEBook-KiCad.kicad_pcb, FN32ROV-XEBook-KiCad.kicad_sch]
2026-07-26 Add IDC/JST/SD-breakout connector schematics
    Places the five new connectors that replace the original FN32ROV SIO
    plug/receptacle and onboard buttons/LEDs: a 12-pin right-angle IDC
    header for the SIO signals, JST breakouts for the relocated LEDs and
    buttons (net names matching XEBookButtonBar's existing swap/bt/rst
    convention), a parallel SD-card breakout header, and a JST for the
    power switch. ERC-clean; remaining warnings are expected single-use
    nets that will resolve once the ESP32 and retained circuitry are wired
    in.
    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
    [FN32ROV-XEBook-KiCad.kicad_sch]
2026-07-26 Add ESP32-WROVER-E, SIO buffers, SD card, and sense/pullup network
    Wires up the retained circuitry cross-checked pin-by-pin against the
    original FN32ROV-1.7.1 schematic: the ESP32-WROVER-E module (real part
    confirmed against the physical board, symbol/footprint sourced from
    Espressif's official KiCad library v3.1.0 for KiCad-9 compatibility),
    both SN74LS07 open-collector SIO buffers, the onboard microSD socket
    wired in parallel with the SD breakout header, and the resistor/cap
    network around the button-sense and pullup nodes.
    ERC is down to 10 violations, all expected for this stage (nets
    waiting on the not-yet-built USB-serial/reset circuit and power
    regulator). Also adds project-level lib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
    [FN32ROV-XEBook-KiCad.kicad_sch]
2026-07-26 Add CP2102N USB-serial, USB-C connector, and ESD protection
    Wires up U2 (CP2102N-A02-GQFN24R), J2 (USB-C 16P using KiCad's stock
    USB2.0 16P receptacle symbol, pins mapped by function since its A/B
    pin naming differs from the original schematic's numbering), the three
    ESD protection diodes on D+/D-/5V, and the supporting network: the
    VBUS-sense divider (R9/R11) feeding the CP2102N's VBUS detect pin, the
    RESET pullup (R10), and the CC2 pulldown (R25) — CC1 is intentionally
    left unconnected, matching the original design.
    U1's USB_RXI/USB_TXO nets are no longer dangling, confirming the
    ESP32<->CP2102N UART link is correctly wired. ERC sits at 11 expected
    violations, all waiting on the not-yet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
    [FN32ROV-XEBook-KiCad.kicad_sch]
2026-07-26 Wire up the USB auto-reset transistor circuit (Q1)
    Places Q1 (UMH3N dual-transistor) using the exact pinout from ROHM's
    datasheet (Datasheets/UMH3NTN.pdf): DTr1 (RTS -> EN) and DTr2 (DTR ->
    GPIO0/BTN_SWAP), each transistor placed as its own unit instance since
    the KiCad symbol models the package the same way as the 74xx gates —
    one placeable unit per transistor sharing a reference designator.
    Adds the EN pullup (R5) and decoupling cap (C2).
    This resolves the deferred ambiguity from the previous commit — the
    datasheet's inner-circuit diagram made the base/collector/emitter
    assignment unambiguous. RTS/DTR/EN are no longer dangling nets, and
    U1's EN pin is no longer undriven. ERC is down t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
    [FN32ROV-XEBook-KiCad.kicad_sch]
2026-07-26 Complete the power path and SD bus pullups — schematic capture done
    Wires up the remaining retained circuitry: the diode-ORed VCC input
    (D7/D8 from USB_5V/SIO_5V), the XC6220B331MR 3.3V regulator with its
    J_PWR-driven enable line (replacing the original onboard slide
    switch), the Q2/Q3 MOSFET pair forming an always-enabled ideal-diode
    power switch to VCC_BUF, and the six pullup resistors on the SD card's
    SPI bus (including DAT1/DAT2, which needed their own pullup nets
    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
    [FN32ROV-XEBook-KiCad.kicad_sch]
2026-07-26 Fix missed R26 (second USB-C CC pulldown) and reconcile against BOM
    R26 is a 5.1K pulldown on CC1, mirroring R25 on CC2 — a fully
    spec-compliant dual-CC-pulldown USB-C sink, not the asymmetric CC1-NC
    setup I'd concluded earlier from a crop that didn't extend far enough
    left to show CC1's actual wire routing. Caught by re-checking the
    original DipTrace file directly.
    Also ran a full reconciliation of every BOM reference designator
    against what's placed in the KiCad schematic, to catch anything else
    missed the same way. Everything is now accounted for: BOM items are
    either placed directly, or intentionally relocated to the new JST/IDC
    connectors (D1-D3 LEDs, S1/S2/S4/S5 switches, J1/J3 SIO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
    [FN32ROV-XEBook-KiCad.kicad_sch]
2026-07-26 Fix real wiring errors found via ground-truth netlist comparison
    The user exported DipTrace's actual netlist (KiCad-format, since
    DipTrace 5+ supports it) and I diffed it against this project's own
    exported netlist. That comparison — matching every (ref, pin) against
    the ground truth rather than trusting my visual reading of the
    schematic image — found genuine errors beyond the R26 miss:
    - Q1 was wired backwards. The real auto-reset circuit cross-couples
    each transistor's emitter to the *other* control signal (E1->RTS,
    B1->DTR, E2->DTR, B2->RTS), not to GND as I'd derived from the
    datasheet's generic inner-circuit diagram.
    - U2's VIO/VDD pins are on their own isolated VDD net —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
    [FN32ROV-XEBook-KiCad.kicad_sch]
2026-07-26 Fix missing 3D models in footprints
    Two gaps found after opening the assembled schematic/PCB in real KiCad:
    the ESP32-WROVER-E footprint pointed at ${KICAD8_3RD_PARTY}, an env var
    that's only populated when a library is installed via KiCad's Plugin
    and Content Manager — since this one was fetched manually via curl, the
    variable was never set and the model silently failed to resolve.
    - Downloaded the real ESP32-WROVER-E .step/.wrl models from Espressif's
    kicad-libraries repo and repointed the footprint at them via
    ${KIPRJMOD}, which always resolves for anyone who clones the repo.
    - The stock IDC-Header_2x06_P2.54mm_Latch_Horizontal and
    USB_C_Receptacle_HCTL_HC-TYPE-C-16P-01A footprin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
    [FN32ROV-XEBook-KiCad.kicad_sch]
2026-07-26 Place all footprints, define board outline, and autoroute the PCB
    Built the PCB layout programmatically via pcbnew's Python API (the same
    approach used for the schematic), driven by the project's own netlist
    export so every pad-to-net assignment traces back to the verified
    schematic rather than being re-derived by hand:
    - Placed all 60 schematic components plus 4 corner mounting holes on a
    120x100mm two-layer board, organized by function (SIO interface on
    the left, ESP32 + support passives in the center, USB/CP2102N on the
    right, power path and SD card zone along the bottom, user-facing LED/
    button JST headers along the top).
    - Found and fixed one real footprint/pad-numbering mismat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
    [FN32ROV-XEBook-KiCad.kicad_pcb]
2026-07-27 Reflow schematic onto a single A2 sheet instead of an 800mm-wide strip
    The schematic was built incrementally block-by-block during earlier
    sessions (connectors, ESP32 core, USB/CP2102N, reset circuit, power
    path), and each block got appended further right on an A4 sheet. The
    result technically had correct connectivity but was a single row of
    content spanning x=40mm to x=850mm — effectively invisible as a
    coherent diagram since no normal page size shows more than a sliver of
    it at once.
    Reorganized into 3 stacked rows (I/O connectors + ESP32/buffers/SD in
    row 1, USB/CP2102N in row 2, power path + PWR_FLAGs in row 3) via rigid
    per-block coordinate translation, keeping every symbol/wire/labe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
    [FN32ROV-XEBook-KiCad.kicad_sch]
2026-07-27 Switch schematic to landscape (A1) with a 3-column layout
    Rearranged the 3 stacked rows from the previous portrait reflow into 3
    side-by-side columns instead (I/O connectors + ESP32/buffers/SD/reset
    on the left, power path + PWR_FLAGs in the middle, USB/CP2102N on the
    right), and switched from A2 portrait to A1 landscape so the wider
    layout fits on one sheet without tiling.
    Same approach as the last reflow: whole-block rigid translation only
    (no re-derivation of individual symbol/wire/label geometry), with
    shift amounts kept as exact multiples of the sheet's 12.7mm grid.
    ERC still clean (1 expected violation: IO12/TDI).
    Claude-Session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
    [FN32ROV-XEBook-KiCad.kicad_sch]
2026-07-27 Fix overlapping labels and two real shorts in the USB/power passives
    While widening the USB decoupling cluster (R9/R10/R11/C4/C5/C7/C8) for
    readability, found two real electrical bugs the tight original spacing
    had been masking:
    - C4's VDD pin landed exactly on U2's own VDD pin stub column once
    widened to x=457.2, shorting VDD to GND through C4/U2's overlapping
    wire segments.
    - C4 and C8, both stacked in the same column 12.7mm apart, each reach
    ~8.9mm toward the other via their pin stubs — closer than 17.8mm
    needed, so their VDD and GND stubs directly overlapped.
    Both were real overlaps, not just visual — confirmed by reproducing
    each via bisection against the last known-good c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
    [FN32ROV-XEBook-KiCad.kicad_sch]
2026-07-27 Move resistor/cap reference & value beside the body, fix long-label overlaps
    Based on the user's manual fix to R10 in the KiCad GUI: for vertical R/C
    parts, keep the symbol itself at rotation 0 (unchanged) but move
    Reference/Value to the left/right of the body (rotated 90°, ~2.54mm
    offset) instead of above/below. This keeps them out of the path of the
    net-name labels extending vertically from the pins, which is what was
    causing "smashed together" text throughout the sheet.
    That fix alone wasn't sufficient though: net labels that read "backward"
    from their stub anchor (see label_orientation's "right"-justify case)
    sweep toward the component body/opposite pin, and 5.08mm of stub isn't
    enough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
    [FN32ROV-XEBook-KiCad.kicad_sch]
2026-07-27 Rotate all resistors/caps 90deg CW to match landscape orientation
    Based on the user's manual rotation of R2 in the KiCad GUI: symbol
    rotation 0->270, pins swap from vertical (top/bottom) to horizontal
    (left/right), Reference/Value move from beside the body to above/below,
    and net-name labels use a label angle/justify convention that's the
    mirror image of the normal horizontal-pin case (confirmed empirically
    against R2's saved file, since it doesn't match a simple rotation of
    the existing convention).
    This required much more than rotating symbols in place. Horizontal
    labels now sweep sideways instead of vertically, and every column
    pitch in the schematic had been tuned for vertical-sweep cle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
    [FN32ROV-XEBook-KiCad.kicad_sch]
2026-07-27 Complete PCB routing and fix component/footprint errors
    - Fix C12: correct value/footprint to 47uF 10V Tantalum 7343 (was
    mistakenly authored as 4.7uF 10V ceramic 0402)
    - Fix Q2/Q3 pin numbering: Device:Q_PMOS/Q_NMOS symbols use G/D/S pin
    numbers but their SOT-23 footprints use 1/2/3, so no net was ever
    assigned to either part's pads. Remapped per the original DipTrace
    netlist's pin-to-function mapping (1=G, 2=S, 3=D).
    - Assign missing Footprint properties for D4-D8, J2, Q1-Q3, SD1, U1-U5
    so PCB stays in sync with the schematic via Update PCB from Schematic
    - Complete PCB routing - all nets connected, 0 DRC errors
    - Add scoped design rule easing J2's NPTH-to-GND-pad hole clearance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
    [FN32ROV-XEBook-KiCad.kicad_pcb, FN32ROV-XEBook-KiCad.kicad_sch]
2026-07-28 Swap external SD header to JST PH, add missing R11/R17, resize mounting holes to M2, add antenna notch, switch to WROVER-IE, center back logo
    - J_SD1: replace 2.54mm pin header with JST PH 7-pin (matches BTN/LED/PWR_SW JST connectors)
    - Add R11 (CP2102 VBUS-sense) and R17 (SPI MISO pull-up), previously missing from PCB despite valid schematic footprints
    - MH1-MH4: resize from 2.5mm bare holes to MountingHole_2.2mm_M2
    - Add J2 USB-C NPTH clearance rule and SD1 board-edge clearance rule to .kicad_dru
    - Cut board-edge notch under U1's antenna keepout zone to remove FR4 substrate from under the ESP32 antenna
    - U1: ESP32-WROVER-E to ESP32-WROVER-IE-N16R8 (adds U.FL external antenna option alongsi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
    [FN32ROV-XEBook-KiCad.kicad_pcb, FN32ROV-XEBook-KiCad.kicad_sch]
2026-07-28 Normalize 10k/10K resistor value casing, add fab output for JLCPCB assembly order
    - Normalize R1-R3/R6/R12/R22 Value from "10k" to "10K" so the BOM groups
    correctly with the other 10K resistors instead of splitting into two lines
    - Add Fab/ with Gerbers, PTH/NPTH drill files, pick-and-place, and BOM
    (grouped + JLCPCB-ready with LCSC part numbers) for the v1.0 assembly order
    [FN32ROV-XEBook-KiCad-BOM-JLCPCB.csv, FN32ROV-XEBook-KiCad-BOM.csv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]
2026-07-29 Refresh JLCPCB assembly export (BOM + CPL)
    Claude-Session: https://claude.ai/code/session_011E5FphyrLWBpYvbXpCPZfr
    [FN32ROV-XEBook-KiCad-BOM-JLCPCB.csv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]
2026-07-29 Resize R13 to 2.7k for the LED boards green WiFi LED, document the LED board interface
    The WiFi status LED moved to the new FN32ROV-XEBook-LED-KiCad daughter board and
    changed color from white to green, which has a lower forward voltage (~2.2V vs
    ~2.9V). R13 needed to grow from 1k to 2.7k to keep the current in the same range
    as the original design. Also documents the sibling LED board repo and the
    per-channel resistor rationale in CLAUDE.md.
    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
    [FN32ROV-XEBook-KiCad.kicad_pcb, FN32ROV-XEBook-KiCad.kicad_sch]
2026-07-29 Re-export Fab outputs for R13 2.7k change
    R13 (WiFi LED current-limit resistor) changed from 1k to 2.7k for the
    LED board's green D1. Regenerated gerbers, drill files, position file,
    and both JLCPCB assembly files (BOM, CPL) from the updated board;
    sourced LCSC C413089 (Panasonic ERJ2RKF2701X, 2.7k 0402 1%) for R13,
    matching the existing Panasonic ERJ2R sourcing used elsewhere in this
    BOM. Gerbers/drill are geometrically unchanged (R13's value text lives
    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
    [FN32ROV-XEBook-KiCad-BOM-JLCPCB.csv, FN32ROV-XEBook-KiCad-BOM.csv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]
2026-07-30 Replace D7/D8 diode part to fix SOD-323/SOD-123W package mismatch
    PCBWay's assembly review caught that PMEG2010ER,115 (the part specified
    for D7/D8) is only manufactured in SOD-123W, not the SOD-323 footprint
    used on this board. Rather than swap the PCB footprint (which would
    require re-routing around a nearby USB_D+ trace and re-exporting
    gerbers), swapped the part instead: Nexperia PMEG2010BEA,115
    (LCSC C455041) is a direct electrical equivalent (20V/1A Schottky, low
    Vf) genuinely packaged in SOD-323, matching the existing footprint.
    Board layout and gerbers are unaffected (value text lives on F.Fab).
    Also includes the filled-in Customer Reply column for PCBWay's BOM
    quote questions (this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
    [FN32ROV-XEBook-KiCad-BOM-JLCPCB.csv, FN32ROV-XEBook-KiCad-BOM.csv, FN32ROV-XEBook-KiCad.kicad_pcb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]
2026-08-02 Ground the copper pour, finish the plane, and archive the as-built 1.0 package
    The single F.Cu/B.Cu zone was (net 0) -- a floating flood, not a ground plane.
    Assign it to /GND and complete it:
    - 65 stitching vias on a 3mm grid (GND vias 4 -> 177), placed by deflating the
    filled zone polygon 0.75mm per layer and intersecting F.Cu with B.Cu, so every
    candidate is inherently clearance-safe
    - island_removal_mode -> Always, clearing 67 isolated_copper warnings
    - min_resolved_spokes 2 -> 1; D4.2 and C4.1 set to solid zone connection
    81 -> 8 DRC violations, 0 unconnected. Strictly additive: 64 footprint positions
    byte-identical, tracks 894 -> 894, outline 66.050 x 56.050mm unchanged to 0.1um,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
    [FN32ROV-XEBook-KiCad-BOM-JLCPCB.csv, FN32ROV-XEBook-KiCad-BOM.csv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]
2026-09-20 Match LED brightness (R14 30k, R15 10K) and re-export fab for PCBWay
    WiFi (R13 2.7k, green) was the channel the build is happy with; BT and SIO
    read about twice as bright. Values come from a bench match on the LED board
    at 3.33V with WiFi through its real 2.7k, not from calculation -- estimates
    based on the 50%-dimming tape used as a stopgap landed near 2.4k and were
    far off. The visual match was 9.2k on SIO; 10K was chosen deliberately as
    slightly dimmer and already a basic part on this board.
    R13 WiFi green 2.7k unchanged C413089
    R14 BT blue 1k -> 30k C25776
    R15 SIO orange 1.2k -> 10K C25744
    The 1.0 boards still carry 1k/1.2k and need hand-rework (0402s at y=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
    [FN32ROV-XEBook-KiCad-BOM-JLCPCB.csv, FN32ROV-XEBook-KiCad-BOM-PCBWay.csv, FN32ROV-XEBook-KiCad-BOM-PCBWay.xlsx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]
2026-09-23 Add TP1 SIO audio take-off pad for PokeyMax and re-export fab
    A 2.0mm through-hole pad (1.0mm drill) on SIO_AUDIN at (80.475, 56.475),
    routed back to J_SIO1 pad 10, so the PokeyMax J2 pin 4 wire has a proper
    solder point instead of being tacked onto the back of the IDC header.
    Sits in the open area right of J_SIO1, centred in a GND stitching-via cell
    above the USB-C connector: 0.82mm to the four nearest vias, 1.1mm clear of
    each via column along the route. Silkscreens SIO_AUDIN; the reference is
    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
    [FN32ROV-XEBook-KiCad-B_Cu.gbl, FN32ROV-XEBook-KiCad-B_Mask.gbs, FN32ROV-XEBook-KiCad-B_Paste.gbp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]
2026-10-16 Silkscreen: add pin-1 markers to the cable headers
    Marks pin 1 on J_BTN1, J_LED1 and J_SD1 so the three daughter-board
    cables cannot be seated backwards during assembly.
    Verified against the previous commit: footprints, pads, copper segments,
    vias and zone definitions are all unchanged. Only F.SilkS text was added
    (plus zone refills and uuid churn from the save).
2026-10-16 Nudge the J_SD1 pin-1 marker clear of R2
    Moves the marker 0.5mm left, to (28.5, 34). It stays level with J_SD1
    pad 1 and is now the nearest object to it by distance as well as
    alignment (2.00mm, against 2.55mm to R2).
    Silkscreen only; footprints, pads, copper, vias and zones unchanged.
2026-10-16 Regenerate fab package for the next order
    Re-exported with kicad-cli 9.0.7 to pick up the new pin-1 / connector
    silkscreen. Versioned filenames rather than overwriting the previous
    package, so the wrong zip cannot be uploaded by mistake.
    Copper, paste, mask, drill and outline unchanged; BOM and CPL carried
    over byte-identical since no component moved. See CLAUDE.md for the
    per-board detail.
